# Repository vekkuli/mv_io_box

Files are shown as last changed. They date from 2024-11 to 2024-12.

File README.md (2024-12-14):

# Machine Vision I/O Box
24 V I/O Box with DIO and 5 and 12 V outputs.

This IO box was developed to be a tool for someone who works with different machine vision devices such as cameras, 3D scanners and other sensors.

### Features
- 24 VDC input
- 24 V wire terminal block connector (two different connector sizes)
- GND wire terminal block connector (two different connector sizes)
- Not Connected wire terminal block connector
- 5 V/1 A DC/DC converter + wire terminal block connector
- 12 V/1 A DC/DC converter + wire terminal block connector
- 4 x Digital Output lines with push button and toggle switch. Debounced to roughly 10 ms using RC circuit and Schmitt Trigger. Open Collector output with 2k2 pull-up resistors available via a DIP switch. 3 mm LED indicators.
- 4 x Digital Input connected to 3 mm LED indicators, optional 2k2 pull-up resistors available via a DIP switch.

### Images
*Note that the images below may not be fully up to date with the code!*

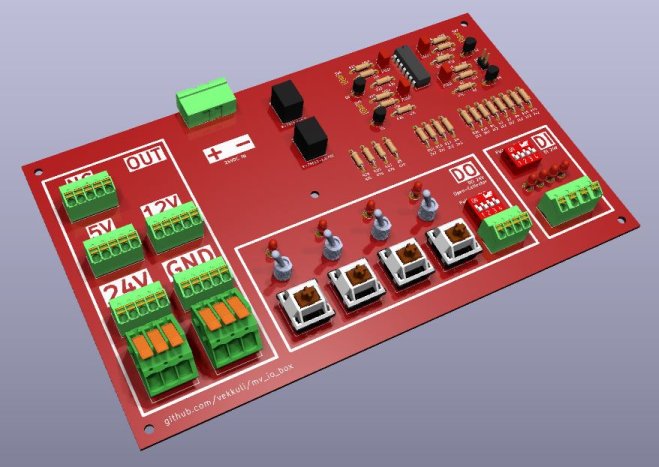
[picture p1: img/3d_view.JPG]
3D View


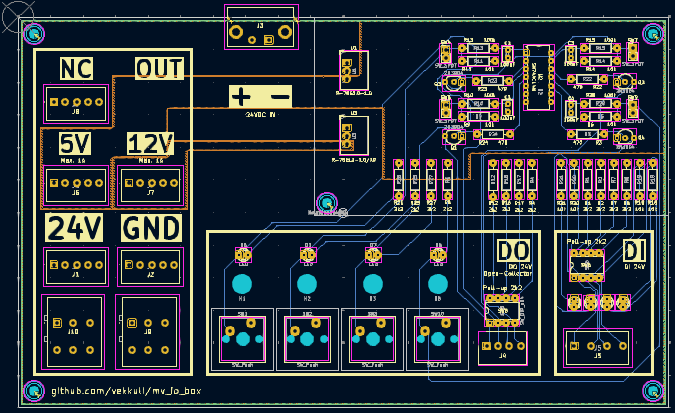
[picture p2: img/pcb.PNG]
PCB


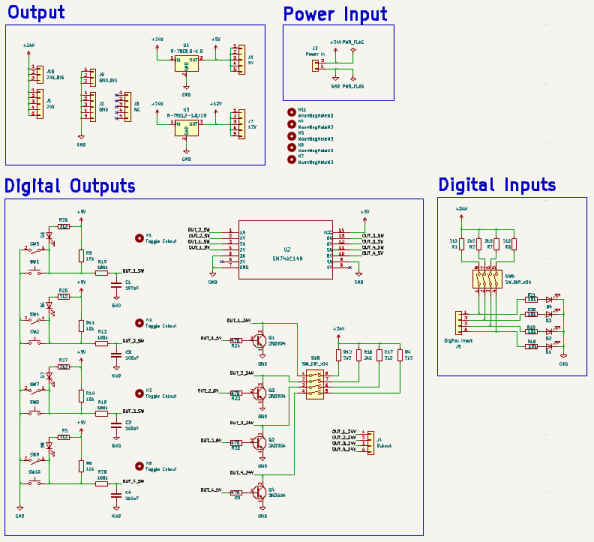
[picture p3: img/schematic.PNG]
Schematic


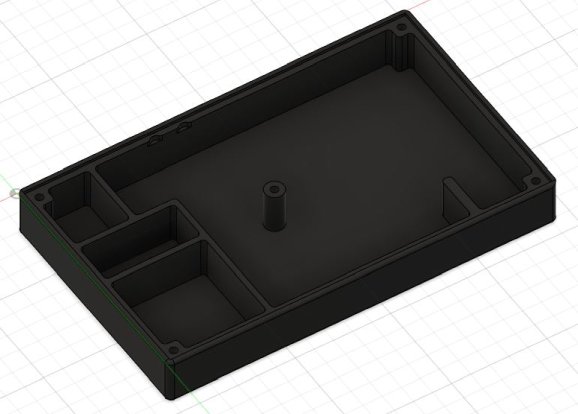
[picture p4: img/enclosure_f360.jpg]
Enclosure
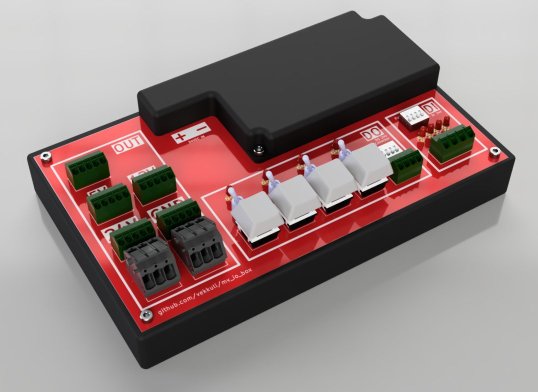
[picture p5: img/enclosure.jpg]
Enclosure


### Contents
- KiCad project including all footprints and 3D models.
- Fabrication outputs, generated using the [Fabrication-Toolkit](https://github.com/bennymeg/Fabrication-Toolkit) plugin.
    - Gerbers (made for JLCPCB)
    - Digikey Cart containing parts for about 5 boards.
- 3D printable enclosure.

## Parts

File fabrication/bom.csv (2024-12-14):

Designator | Footprint | Quantity | Value | LCSC Part #
C1, C2, C3, C4 | C_Rect_L4.6mm_W3.0mm_P2.50mm_MKS02_FKP02 | 4 | 100nF
D1, D2, D3, D4, D5, D6, D7, D8 | LED_D3.0mm | 8 | LED
J1 | Phoenix Contact SPTA 1 5-3,5 - PCB terminal block | 1 | 24V
J10 | Phoenix Contact LPTA 2,5 3-5,0 - PCB terminal block | 1 | 24V_BIG
J2 | Phoenix Contact SPTA 1 5-3,5 - PCB terminal block | 1 | GND
J3 | Phoenix Contact MSTB 2,5 2-GF-5,08 - PCB header | 1 | Power In
J4 | Phoenix Contact SPTA 1 4-3,5 - PCB terminal block | 1 | Output
J5 | Phoenix Contact SPTA 1 4-5,0 - PCB terminal block | 1 | Digital Input
J6 | Phoenix Contact SPTA 1 5-3,5 - PCB terminal block | 1 | 5V
J7 | Phoenix Contact SPTA 1 5-3,5 - PCB terminal block | 1 | 12V
J8 | Phoenix Contact SPTA 1 5-3,5 - PCB terminal block | 1 | NC
J9 | Phoenix Contact LPTA 2,5 3-5,0 - PCB terminal block | 1 | GND_BIG
Q1, Q2, Q3, Q4 | TO-92_Inline_Wide | 4 | 2N3904
R1, R12, R16, R17, R2, R25, R26, R27, R4, R5, R7, R8 | R_Axial_DIN0207_L6.3mm_D2.5mm_P10.16mm_Horizontal | 12 | 2k2
R10, R13, R15, R28 | R_Axial_DIN0207_L6.3mm_D2.5mm_P10.16mm_Horizontal | 4 | 100k
R11, R14, R18, R19, R20, R21, R6, R9 | R_Axial_DIN0207_L6.3mm_D2.5mm_P10.16mm_Horizontal | 8 | 10k
R22, R23, R24, R3 | R_Axial_DIN0207_L6.3mm_D2.5mm_P10.16mm_Horizontal | 4 | 470
SW1, SW10, SW2, SW3 | SW_Cherry_MX_1.00u_PCB | 4 | SW_Push
SW4, SW5, SW7, SW9 | PinHeader_1x02_P2.54mm_Vertical | 4 | SW_SPDT
SW6, SW8 | DIP-8_W7.62mm | 2 | SW_DIP_x04
U1 | Converter_DCDC_RECOM_R-78E-0.5_THT | 1 | R-78E5.0-1.0
U2 | SN74AC14N | 1 | SN74AC14N
U3 | Converter_DCDC_RECOM_R-78E-0.5_THT | 1 | R-78E12-1.0/X9

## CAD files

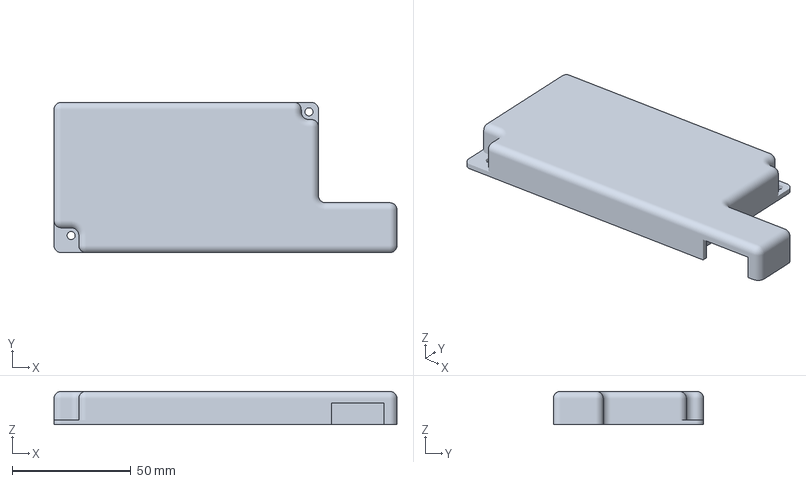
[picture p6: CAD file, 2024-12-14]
enclosure/mv_io_box_top.3mf
144.2 x 63.2 x 14.0 mm

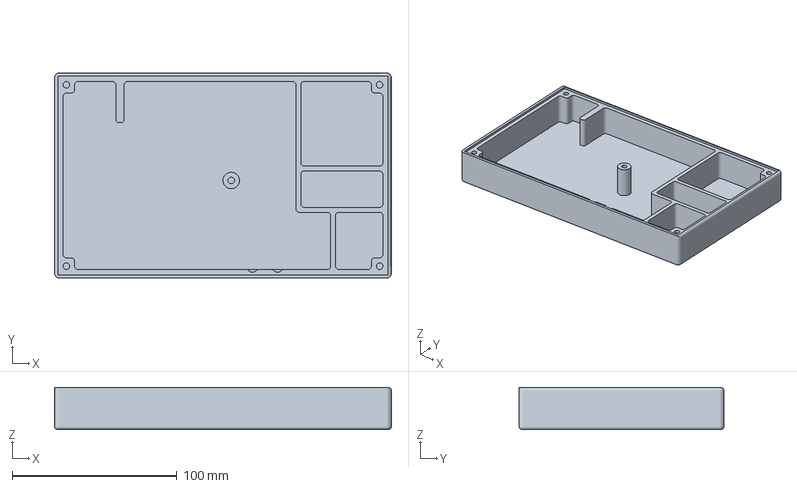
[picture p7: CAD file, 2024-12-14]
enclosure/mv_io_box_enclosure.3mf
204.4 x 124.4 x 25.6 mm

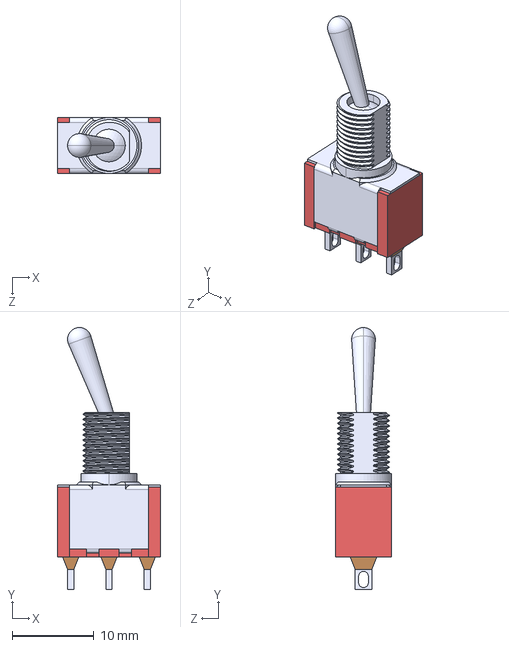
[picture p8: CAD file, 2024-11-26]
kicad_project/3dmodels/SPDT_Toggle_Switch.step
12.7 x 32.1 x 6.86 mm

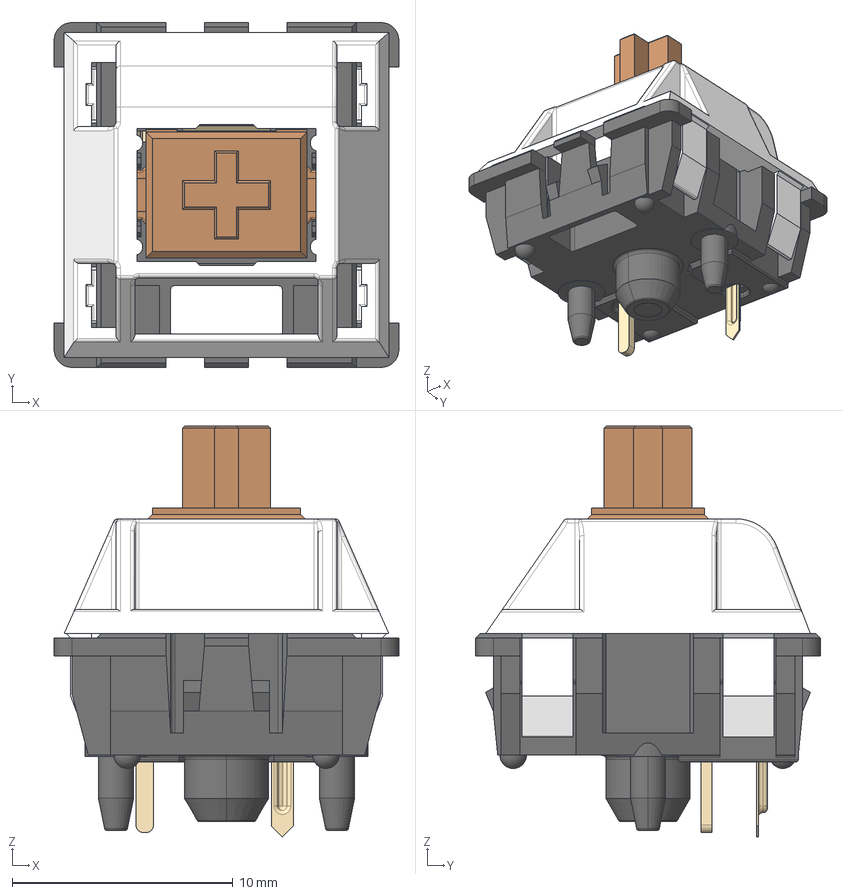
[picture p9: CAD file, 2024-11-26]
kicad_project/3dmodels/SW_Cherry_MX_PCB.stp
15.6 x 15.6 x 18.6 mm

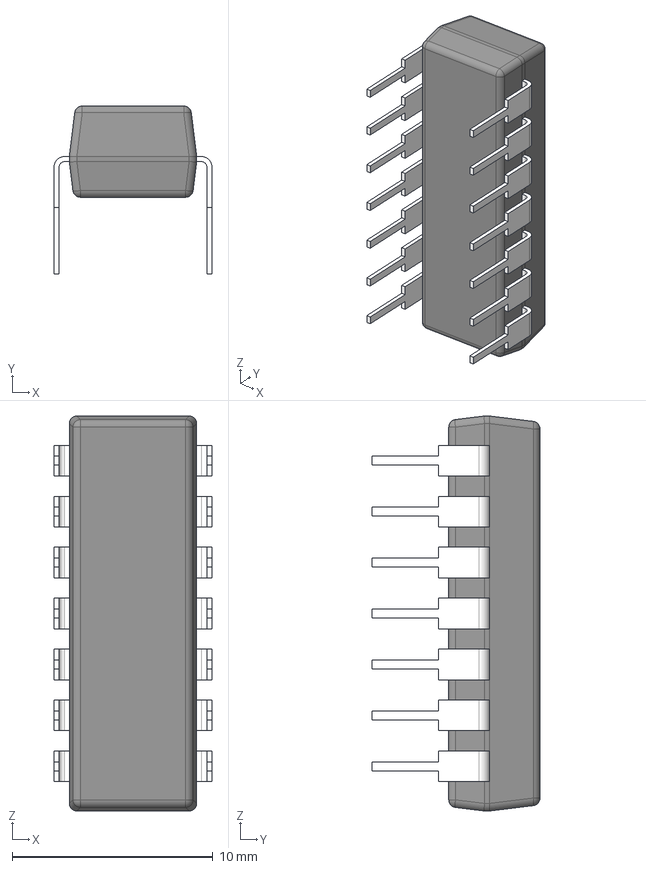
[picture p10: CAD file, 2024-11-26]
kicad_project/3dmodels/N0014A.stp
7.87 x 8.37 x 19.7 mm
BODY_N0014A_AF0
LEAD_N0014A_AF1
LEAD_N0014A x 10
LEAD_N0014A_AF3
LEAD_N0014A_AF0
LEAD_N0014A_AF2

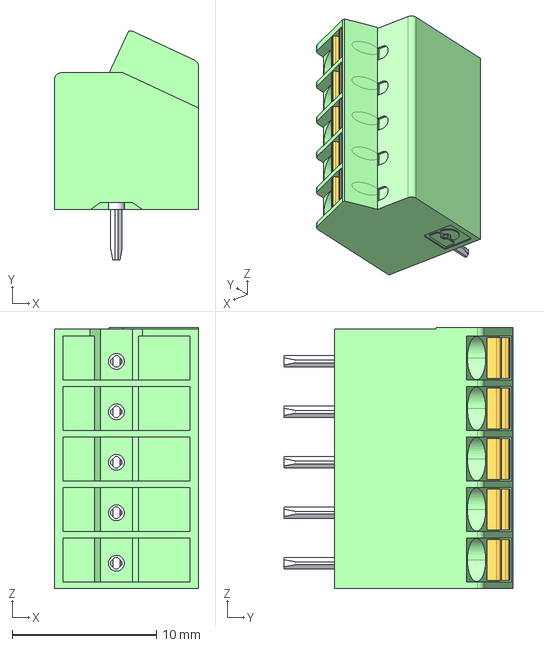
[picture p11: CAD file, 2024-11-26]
kicad_project/3dmodels/1752133.stp
10.00 x 15.9 x 18.1 mm

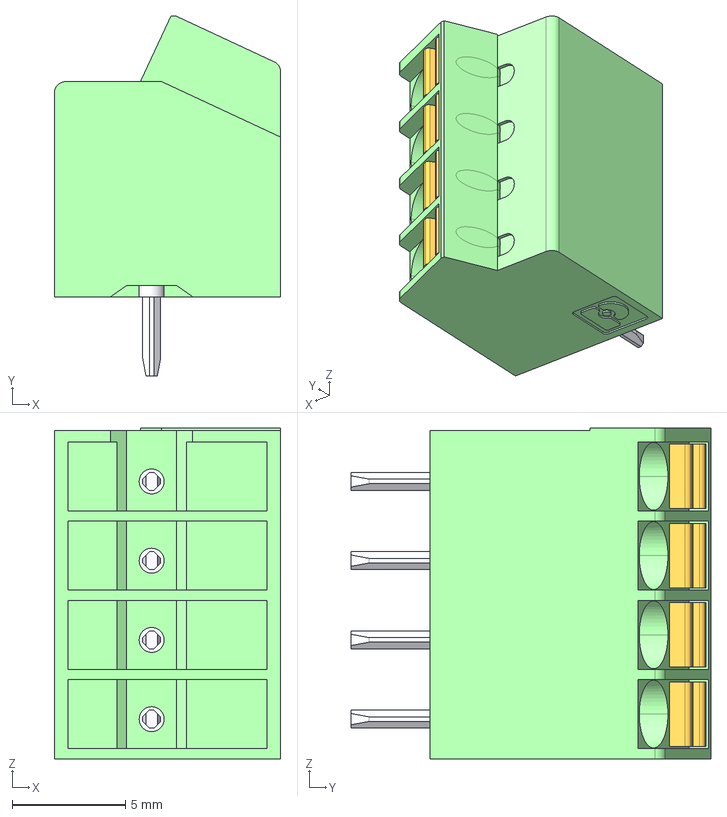
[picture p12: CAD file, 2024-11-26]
kicad_project/3dmodels/1752120.stp
10.00 x 15.9 x 14.6 mm

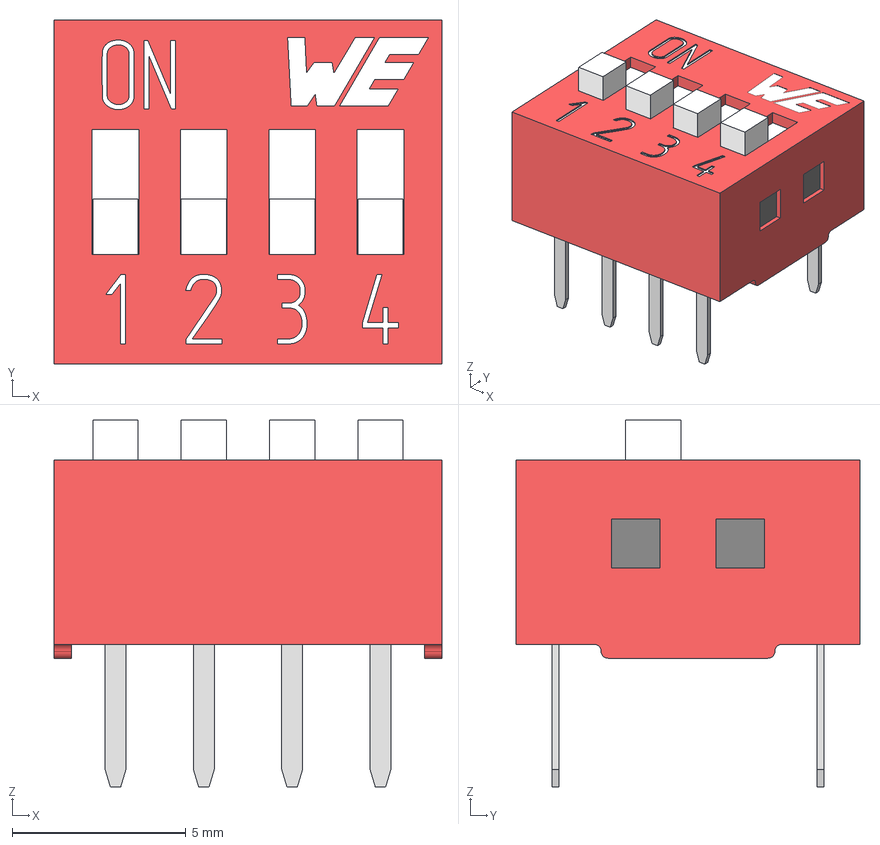
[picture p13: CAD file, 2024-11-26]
kicad_project/3dmodels/418117270904.step
11.2 x 9.90 x 10.6 mm
Base_switch
clip x 4
base

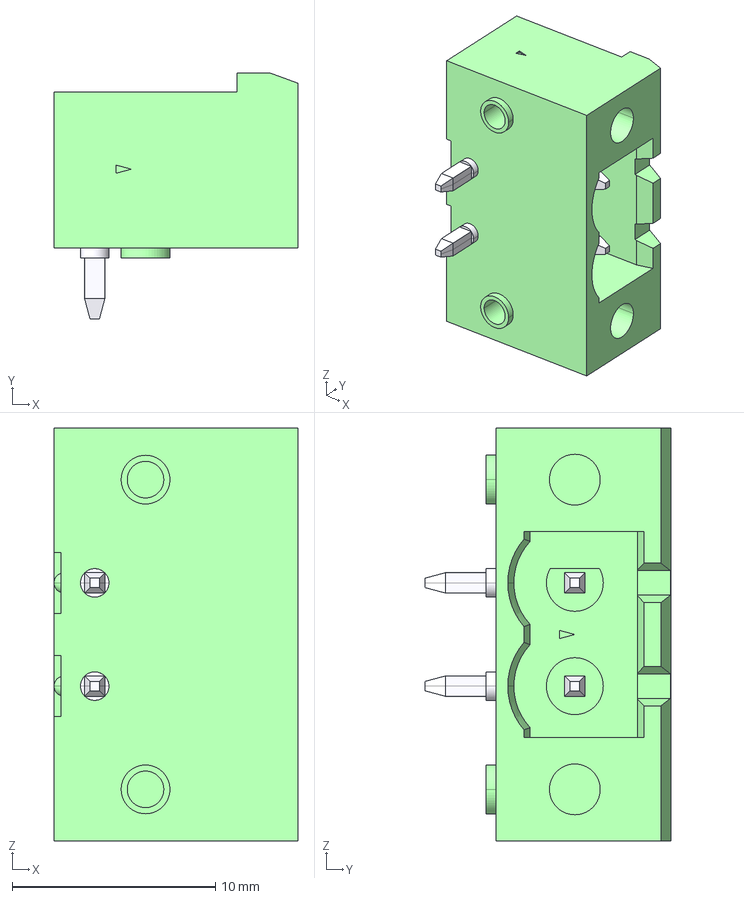
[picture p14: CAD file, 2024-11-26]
kicad_project/3dmodels/1776508.stp
12.0 x 12.1 x 20.3 mm

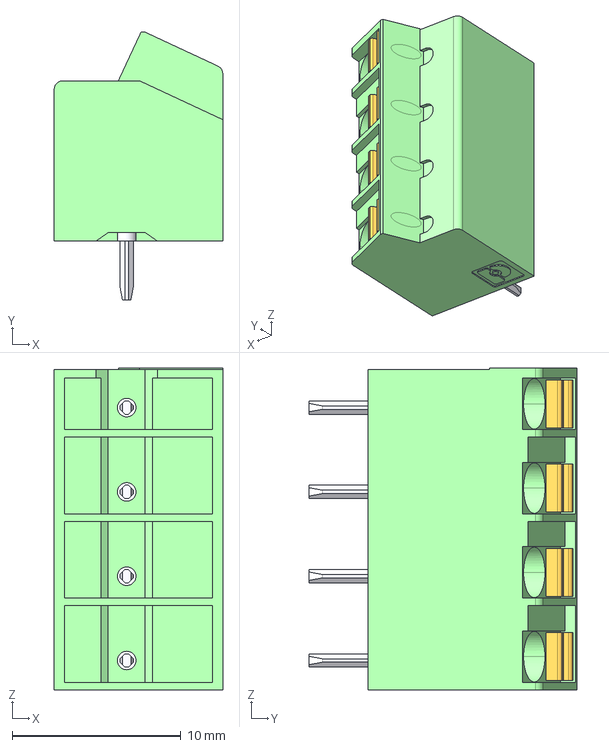
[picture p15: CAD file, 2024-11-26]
kicad_project/3dmodels/1752230.stp
10.00 x 15.9 x 19.1 mm

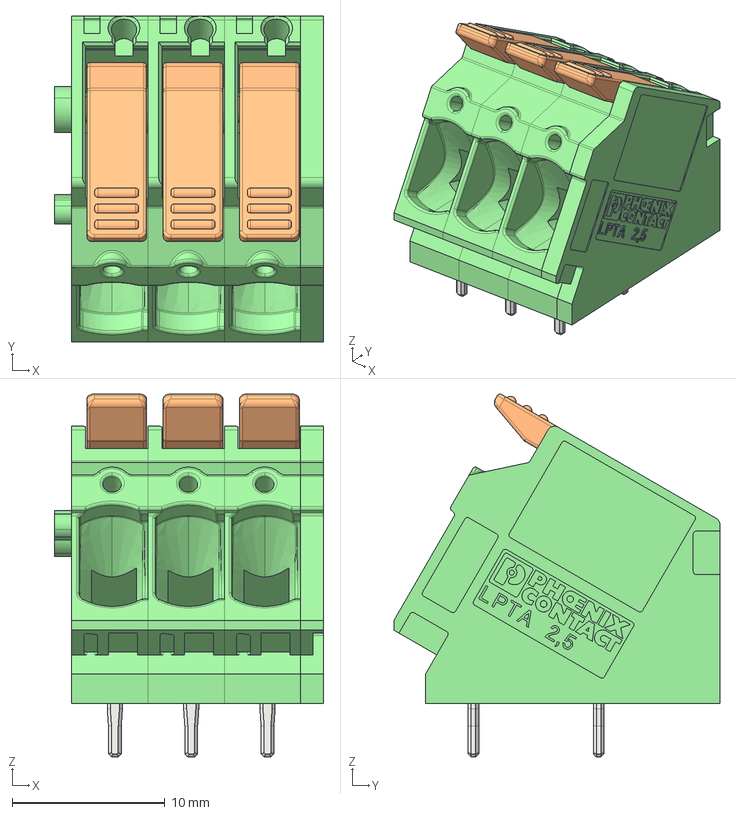
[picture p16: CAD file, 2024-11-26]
kicad_project/3dmodels/1190364.stp
17.6 x 21.4 x 23.8 mm
LP_LPT_2_5_3_50.4 x 6
AC_LPT_2_5_LEVER.2 x 3
PK_LPTA_2_5_5_00 x 3
DK_LPTA_2_5_5_00

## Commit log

2024-11-26 Added bom and digikey_cart files.
    [bom.csv, digikey_cart.csv]
2024-11-27 Fixes #1
    [enclosure.step]
2024-11-27 Added picture of enclosure
2024-12-13 Bug fixes and resistor changes
    Raised LED resistor values from 470 to 2k2 and from 2k2 to 10k.
    Fixed NPN transistor incorrect pin order.
    Fixed LPTA connector footprint pins.
    [io_box.kicad_pcb, io_box.kicad_sch]
2024-12-14 Regenerated fabrication output and updated enclosure model
    [bom.csv, designators.csv, enclosure.step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]
